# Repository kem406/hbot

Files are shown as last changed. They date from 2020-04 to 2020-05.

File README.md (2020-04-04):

# The Tactile theme

 

*Tactile is a Jekyll theme for GitHub Pages. You can [preview the theme to see what it looks like](http://pages-themes.github.io/tactile), or even [use it today](#usage).*

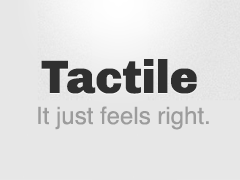
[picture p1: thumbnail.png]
Thumbnail of Tactile


## Usage

To use the Tactile theme:

1. Add the following to your site's `_config.yml`:

    ```yml
    theme: jekyll-theme-tactile
    ```

2. Optionally, if you'd like to preview your site on your computer, add the following to your site's `Gemfile`:

    ```ruby
    gem "github-pages", group: :jekyll_plugins
    ```

## Customizing

### Configuration variables

Tactile will respect the following variables, if set in your site's `_config.yml`:

```yml
title: [The title of your site]
description: [A short description of your site's purpose]
```

Additionally, you may choose to set the following optional variables:

```yml
show_downloads: ["true" or "false" to indicate whether to provide a download URL]
google_analytics: [Your Google Analytics tracking ID]
```

### Stylesheet

If you'd like to add your own custom styles:

1. Create a file called `/assets/css/style.scss` in your site
2. Add the following content to the top of the file, exactly as shown:
    ```scss
    ---
    ---

    @import "{{ site.theme }}";
    ```
3. Add any custom CSS (or Sass, including imports) you'd like immediately after the `@import` line

*Note: If you'd like to change the theme's Sass variables, you must set new values before the `@import` line in your stylesheet.*

### Layouts

If you'd like to change the theme's HTML layout:

1. [Copy the original template](https://github.com/pages-themes/tactile/blob/master/_layouts/default.html) from the theme's repository<br />(*Pro-tip: click "raw" to make copying easier*)
2. Create a file called `/_layouts/default.html` in your site
3. Paste the default layout content copied in the first step
4. Customize the layout as you'd like

### Overriding GitHub-generated URLs

Templates often rely on URLs supplied by GitHub such as links to your repository or links to download your project. If you'd like to override one or more default URLs:

1. Look at [the template source](https://github.com/pages-themes/tactile/blob/master/_layouts/default.html) to determine the name of the variable. It will be in the form of `{{ site.github.zip_url }}`.
2. Specify the URL that you'd like the template to use in your site's `_config.yml`. For example, if the variable was `site.github.url`, you'd add the following:
    ```yml
    github:
      zip_url: http://example.com/download.zip
      another_url: another value
    ```
3. When your site is built, Jekyll will use the URL you specified, rather than the default one provided by GitHub.

*Note: You must remove the `site.` prefix, and each variable name (after the `github.`) should be indent with two space below `github:`.*

For more information, see [the Jekyll variables documentation](https://jekyllrb.com/docs/variables/).

## Roadmap

See the [open issues](https://github.com/pages-themes/tactile/issues) for a list of proposed features (and known issues).

## Project philosophy

The Tactile theme is intended to make it quick and easy for GitHub Pages users to create their first (or 100th) website. The theme should meet the vast majority of users' needs out of the box, erring on the side of simplicity rather than flexibility, and provide users the opportunity to opt-in to additional complexity if they have specific needs or wish to further customize their experience (such as adding custom CSS or modifying the default layout). It should also look great, but that goes without saying.

## Contributing

Interested in contributing to Tactile? We'd love your help. Tactile is an open source project, built one contribution at a time by users like you. See [the CONTRIBUTING file](docs/CONTRIBUTING.md) for instructions on how to contribute.

### Previewing the theme locally

If you'd like to preview the theme locally (for example, in the process of proposing a change):

1. Clone down the theme's repository (`git clone https://github.com/pages-themes/tactile`)
2. `cd` into the theme's directory
3. Run `script/bootstrap` to install the necessary dependencies
4. Run `bundle exec jekyll serve` to start the preview server
5. Visit [`localhost:4000`](http://localhost:4000) in your browser to preview the theme

### Running tests

The theme contains a minimal test suite, to ensure a site with the theme would build successfully. To run the tests, simply run `script/cibuild`. You'll need to run `script/bootstrap` one before the test script will work.

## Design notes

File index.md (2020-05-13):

---
layout: default
title:  "Rob Hart's H-Bot"
---

<iframe src="https://www.youtube.com/embed/vSqIZIaWzNs"
    width="560"
    height="315"
    frameborder="0"
    allowfullscreen>
</iframe>

This drawing robot incorporates an H-Bot gantry in order to move a writing instrument across a paper sheet using only two stepper motors.

# Why use an H-Bot?

A [cartesian coordinate robot](https://en.wikipedia.org/wiki/Cartesian_coordinate_robot) normally uses 3 motors to move an end effector across an x-y plane. This can be seen on machines like the MakerBot 3D printer and the desktop version of the ShopBot.

The H-Bot gantry design allows for the same x-y movement to be achieved using only 2 stepper motors. This makes the design advantageous for large-scale deployment in manufacturing, potentially lowering assembly costs, but more importantly it allows for the moving axes to be freed of carrying the weight of one of the stepper motors. Note that all motors of the drawing robot are immobile and anchored at the base - this is not something you would normally see on an x-y machine!

## How it works

Movement on the x-y plane is completely dictated by whether the two stepper motors turn in the same direction, or rotate opposite of each other.

The left motor turning clockwise and the right motor turning counter-clockwise, for example, causes increased tension on the bottom of the x-axis and relaxed tension above the x-axis. This causes a net effect of downward motion.

If both motors are turning clockwise, this causes tension on the left side of the end effector to increase, while the tension on the right side relaxes. This causes a net effect of the end effector moving to the left.

A more rigorous mathematical model of an H-Bot's movement can be found [here](https://www.icvr.ethz.ch/ConfiguratorJM/publications/MODELING_A_132687166151936/3314_mod.pdf).

The crisscrossing of the drive belt is not necessary for the H-Bot design, though it greatly stabilizes the wobbliness of the x-axis.

# Hardware

## Circuits

* [ATSAMD11 Breakout Board](https://roberthart56.github.io/SCFAB/SC_lab/Electronics/Microcontrollers/ATSAMD11/Advanced_circuits_board/index.html)

* [ATSAMD11 H-Brige Boards](https://roberthart56.github.io/SCFAB/SC_lab/Output_Devices/SAMD11_stepper/index.html)

## 3D-printed hardware

<html>
    <head>
        <title>Roller</title>
    </head>

    <body>

        <script src="stl_viewer.min.js"></script>        
        <script>
            var stl_viewer=new StlViewer
            (
                document.getElementById("stl_cont"),
                {
                    zoom:50,
                    bgcolor:"white",
                    models:
                    [
                        {filename:"roller.stl", color:"#ffff00", display:"smooth", rotationx:0.5, rotationy:0.5, rotationz:0.5, animation:{delta:{rotationx:1, msec:1000, loop:true}}}

                    ]
                }
            );
        </script>

    </body>
</html>

<html>
    <head>
        <title>Pen Holder</title>
    </head>

    <body>

        <script src="stl_viewer.min.js"></script>        
        <script>
            var stl_viewer=new StlViewer
            (
                document.getElementById("stl_cont"),
                {
                    zoom:70,
                    bgcolor:"white",
                    models:
                    [
                        {filename:"penholder1.stl", color:"#ffff00", display:"flat", rotationx:0.5, rotationy:0.5, rotationz:0.5, animation:{delta:{rotationx:1, msec:1000, loop:true}}}

                    ]
                }
            );
        </script>

    </body>
</html>

<html>
    <head>
        <title>Footpad</title>
    </head>

    <body>

        <script src="stl_viewer.min.js"></script>        
        <script>
            var stl_viewer=new StlViewer
            (
                document.getElementById("stl_cont"),
                {
                    zoom:70,
                    bgcolor:"white",
                    models:
                    [
                        {filename:"footpad.stl", color:"yellow", display:"flat", rotationx:0.5, rotationy:0.5, rotationz:0.5, animation:{delta:{rotationx:1, msec:1000, loop:true}}}

                    ]
                }
            );
        </script>

    </body>
</html>

### Rollers

The rollers used for this robot were designed by Jake Read for the machine design portion of MIT's How to Make Almost Anything class. More information can be found [here](https://gitlab.cba.mit.edu/jakeread/machineweek-2019). The .stl file for the roller itself can be downloaded [here](https://kem406.github.io/hbot/roller.stl).

### End effector

The end effector was designed to hold a pen-sized marker which fits through the shaft. Two small rectangle-shaped reliefs were incorporated into the right-hand and left-hand sides of the end effector—these are designed to snugly contain (with a small application of superglue) a small cut-off portion of the drive belt.

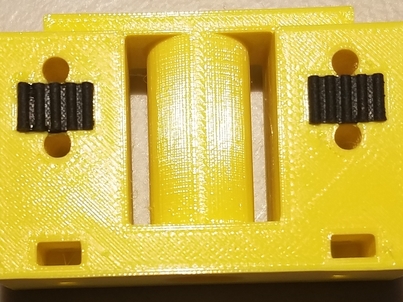
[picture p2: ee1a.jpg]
ee1a
[](https://kem406.github.io/hbot/ee1b.jpg)

These embedded bits of drive belt can then act as the "teeth" that holds the main drive belt in place.

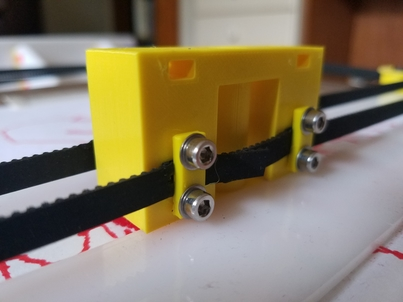
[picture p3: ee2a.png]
ee2a
[](https://kem406.github.io/hbot/ee2b.jpg)

With a 3d-printed fastener (.stl can be downloaded [here](https://kem406.github.io/hbot/fastener.stl)) and some M3 screws and washers, the main drive belt can be fastened on top of the "teeth."

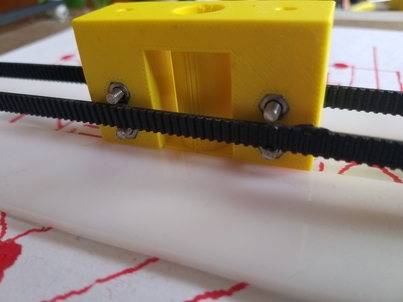
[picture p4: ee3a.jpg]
ee3a
[](https://kem406.github.io/hbot/ee3b.jpg)

The end effector was designed to allow two M3 nuts to be embedded snugly in place for this purpose. Two more M3 nuts can be fitted inside two slots towards the top of the end effector; this allows for future additions (such as a solenoid) to be bolted on top.

The .stl file for the end effector can be downloaded [here](https://kem406.github.io/hbot/penholder1.stl).

### Footpads

These hourglass-shaped footpads are nothing special and exist entirely to support the back end of the robot. The .stl file for the footpads can be downloaded [here](https://kem406.github.io/hbot/footpad.stl).

## Miscellaneous hardware (non-exhaustive)

* Fiberglass board
* M3 hardware
* Drive belt
* [Unipolar stepper motors](https://www.jameco.com/z/42BYGH404-R-Unipolar-Stepper-Motor-12VDC-400mA_238538.html)
* 12-volt power supply

# Software

All of the following programming was done with the Arduino IDE with the board parameter set to "Generic D11C14A."

## Main break-out board code

```

/*
 * xy_sketcher.ino  Rob Hart 1/8/20. Modified by Ken Michalek 4/26/20. Code to create byte
 *packets for stepper motor boards to control an h-bot drawing machine as an "etch-a-sketch"
 */

int current_x = 0;    //calculated on the basis of steps sent.
int current_y = 0;    //calculated on the basis of steps sent.

void setup() {
   Serial1.begin(230400);     //uses USART on rx/tx pins.
   Serial.begin(0);           //USB serial
}
/*
 * Function to send stepper motor bytes based on requested x and y increments.
 */
void step(int dx, int dy){
  int delta_1;
  int delta_2;
  uint8_t byte_1;
  uint8_t byte_2;
  uint8_t step_1_dir;
  uint8_t step_2_dir;

  delta_1=dx+dy;        //This is the increment for motor 1, defined this way for h-bot geometry
  delta_2 =dx-dy;       //This is the increment for motor 2, defined this way for h-bot geometry

  //add more motors, or add code to send a command to another board, such as an 'end effector'.

  if (delta_1 >= 0) step_1_dir = 1;   //determine sign of steps for 1
  else step_1_dir = 0;

  if (delta_2 >= 0) step_2_dir = 1;   //determine sign of steps for 2
  else step_2_dir = 0;

  byte_1 = 128 * step_1_dir + 16 + abs(delta_1);    //this packs direction, address and step number into one byte. address = 1
  byte_2 = 128 * step_2_dir+ 2*16 + abs(delta_2);   //this packs direction, address and step number into one byte. address = 2
  Serial1.write(byte_1);
  Serial1.write(byte_2);
}

void loop() {
  int input_x;      //reading of ADC
  int setpoint_x;   //derived from ADC reading
  int deficit_x;   // difference between setpoint and calculated x

  int input_y;      //reading of ADC
  int setpoint_y;   //derived from ADC reading
  int deficit_y;   // difference between setpoint and calculated x
  int f = 8;      //keep number of steps above this number; fine tune for noise reduction
  int g = 11;     //keep number of steps below this number; fine tune for noise reduction

/*
 *Check x potentiometer, and calculate needed steps to match pen with requested x.
 */
input_x = analogRead(2);
  setpoint_x = 1023 - input_x;
  deficit_x = setpoint_x - current_x;

/*
 *Keep number of steps less than g and more than f (for noise reduction).
 */
  if (deficit_x > g) deficit_x = g;
  if (deficit_x < -g) deficit_x = -g;
  if ((deficit_x <= f) & (deficit_x  >= -f)) deficit_x = 0;

/*
 *Check y potentiometer, and calculate needed steps to match pen with requested y.
 */
  input_y = analogRead(4);
  setpoint_y = 1023 - input_y;
  deficit_y = setpoint_y - current_y;

/*
 *Keep number of steps less than g and more than f (for noise reduction).
 */
  if (deficit_y > g) deficit_y = g;
  if (deficit_y < -g) deficit_y = -g;
  if ((deficit_y <= f) & (deficit_y  >= -f)) deficit_y = 0;

  step(deficit_x , deficit_y);          //step requested amounts
  current_x = current_x + deficit_x;    //update x
  current_y = current_y + deficit_y;    //update y

   delay(20);
   Serial.print(current_x);               //print out current values.
   Serial.print(", ");
   Serial.println(current_y);
  }
```

## Stepper motor board code

This code is given to both stepper motor boards. Note that it is important that one board's uint8_t address is set to 1 and the other is set to 2. This is because both boards are fed the same serial code, and this is the only way for the two motors to tell which part of the instructions they should be following (otherwise, they wouldn't be able to rotate in different directions when we want the robot to move up and down).

```
/*
Jan 7, 2020.  Rob Hart.  samd11_stepper_3
Program to drive stepper in response to one byte transferred into USART NO. 1.
MSB(7): direction.
6-4: address.
3-0: number of steps to take.
In this program, step time is fixed.

*/
int Aplus = 15;   //corresponds to h-bridge input pin +
int Aminus = 14;   //corresponds to h-bridge input pin -
int Bplus = 8;   //corresponds to h-bridge input pin +
int Bminus = 5;   //corresponds to h-bridge input pin -
int LED_G = 4;    //LEDs are attached to pins to give a visual indication of direction and step
int LED_R = 2;

int step_num = 1;
uint16_t step_count = 0;      //number of steps since program began.
uint8_t pulse_count = 0;     //The variable with range 0-3 that determines which motor state to
uint8_t rec_byte = 0;         //The byte received from USART
bool direction = true;        //True corresponds to incrementing pulse count.
//uint8_t address = 2;      //This value is unique to a given board. Ranges 0-7.
uint8_t address = 1;      //This value is unique to a given board. Ranges 0-7.

void setup() {
  Serial1.begin(230400);
  SerialUSB.begin(0);
  pinMode(Aplus, OUTPUT);
  pinMode(Aminus, OUTPUT);
  pinMode(Bplus, OUTPUT);
  pinMode(Bminus, OUTPUT);
  pinMode(LED_G, OUTPUT);
  pinMode(LED_R, OUTPUT);

}
/*
The following functions energise the windings, in order defined as positive stepping
*/
void pulse_0(){
  digitalWrite(Aplus,HIGH);
  digitalWrite(Bplus,HIGH);
}

void pulse_1(){
  digitalWrite(Aminus,HIGH);
  digitalWrite(Bplus,HIGH);
}

void pulse_2(){
  digitalWrite(Aminus,HIGH);
  digitalWrite(Bminus,HIGH);
}

void pulse_3(){
  digitalWrite(Aplus,HIGH);
  digitalWrite(Bminus,HIGH);
}
/*
The following function turns off all windings.
*/
void all_off() {
  digitalWrite(Aplus,LOW);
  digitalWrite(Aminus,LOW);
  digitalWrite(Bplus,LOW);
  digitalWrite(Bminus,LOW);
}

void loop() {

  while (!Serial1.available()){       //wait until serial is available.
  }

  rec_byte =  Serial1.read();

  if ((rec_byte & 0b01110000) >> 4 == address){     //Bitwise detection of address using three-digit mask and shifting.
                                                    //If address is detected, step the motor. Otherwise, go back and wait for another byte.
    digitalWrite(LED_G, HIGH);                      //Green LED indicates start of stepping.

    direction = rec_byte & 0b10000000;        //set the boolean direction to be true or false using only the most significant bit.
    if (direction) digitalWrite(LED_R, HIGH);     //use LED as a visual indicator of + direction.
    else digitalWrite(LED_R, LOW);

    step_num = rec_byte & 0b00001111;      //strip off lower half-byte

    /*
    The following loop steps the motor for 'step_num' steps.
    */
    for(int i=0; i<step_num; i++){

      if (direction) step_count++;
      else step_count--;

      pulse_count = step_count%4;       //use the modulo function to keep track of which motor state to use.

      SerialUSB.println(step_count);    //print out overall step count.

      all_off();
      delayMicroseconds(10);

      if (pulse_count == 0) pulse_0();
      if (pulse_count == 1) pulse_1();
      if (pulse_count == 2) pulse_2();
      if (pulse_count == 3) pulse_3();

      delayMicroseconds(5000);      //microseconds.  This, together with unknown overhead, defines the step time.
    }
    digitalWrite(LED_G, LOW);    //done with stepping.
      }

 }
```

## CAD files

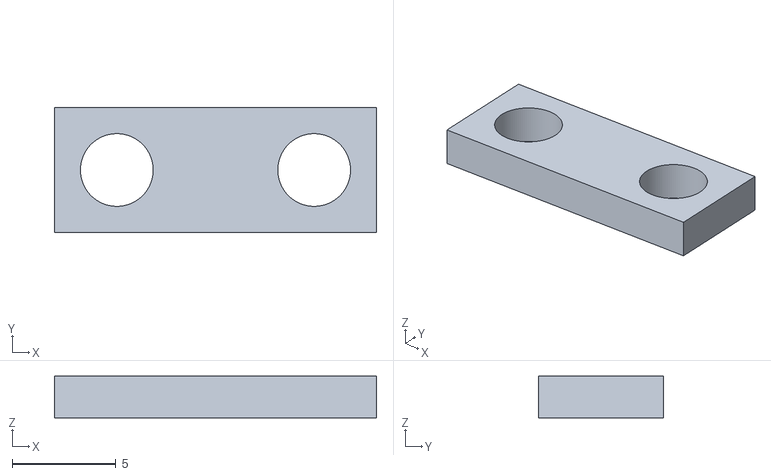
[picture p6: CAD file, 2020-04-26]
fastener.stl
15.5 x 6.00 x 2.00

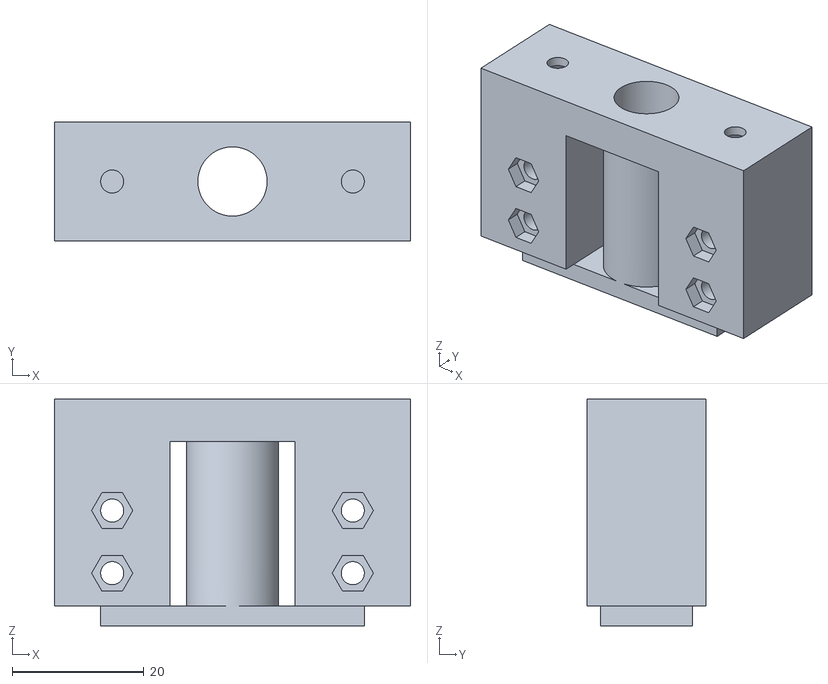
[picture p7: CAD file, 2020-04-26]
penholder1.stl
54.0 x 18.0 x 34.4

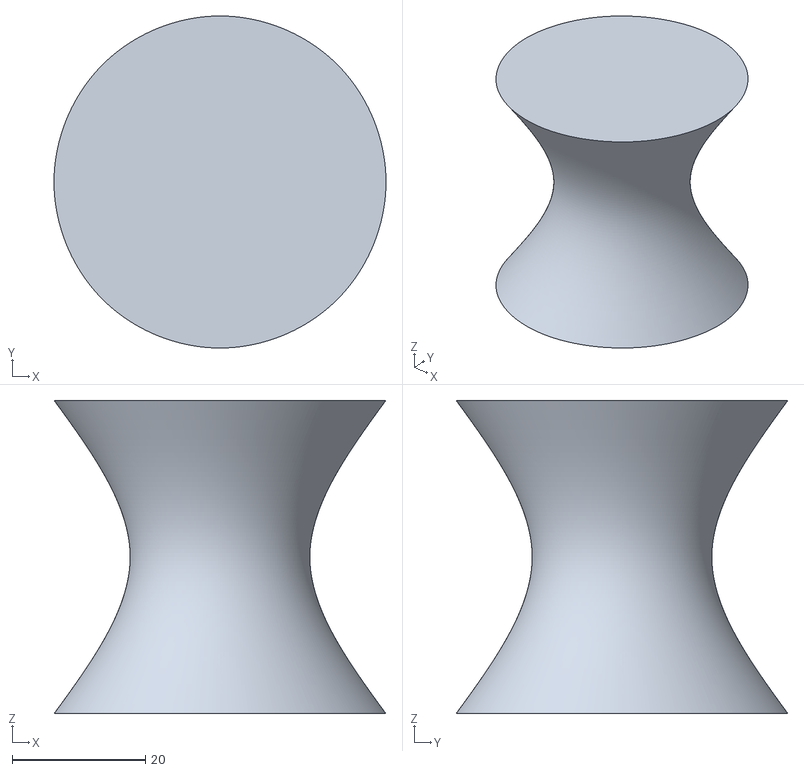
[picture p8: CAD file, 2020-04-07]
footpad.stl
49.9 x 49.9 x 47.1

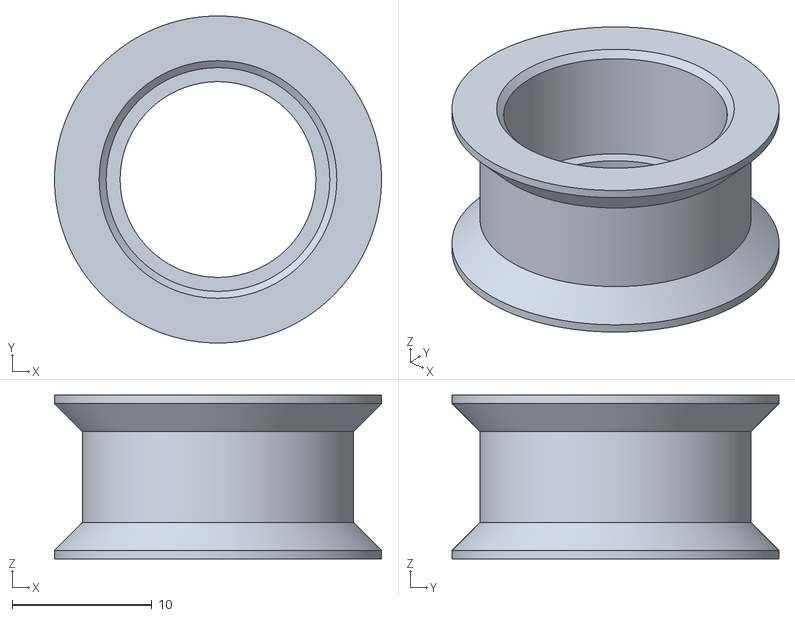
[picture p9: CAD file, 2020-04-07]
roller.stl
23.4 x 23.4 x 11.7

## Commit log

2020-04-07 javascript roller
    [hbot_pen_holder_2 v2.stl, roller.stl]
2020-04-26 new model
    [penholder0.stl, penholder1.stl]
2020-04-26 .stl links
    [penholder0.stl]
